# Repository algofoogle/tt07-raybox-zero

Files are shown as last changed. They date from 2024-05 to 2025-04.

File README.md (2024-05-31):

   

# raybox-zero for TT07 (Tiny Tapeout 07) - Resubmission updated from TT04

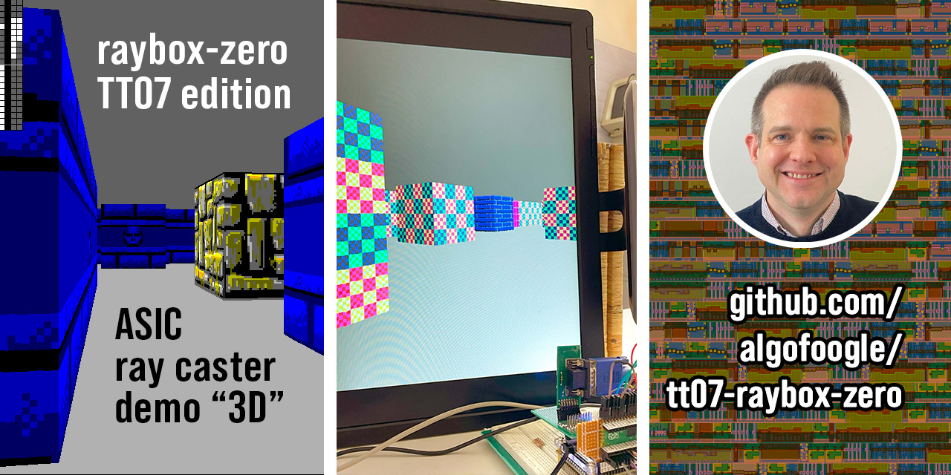
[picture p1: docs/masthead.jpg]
TT07 raybox-zero showing 3D views in simulation and on an FPGA


This is a resubmission of a very simple ray caster demo (sort of like Wolf3D rendering) driving a VGA display without a framebuffer (i.e. by 'racing the beam').

It was originally submitted to TT04, but due to a synthesis bug in the OpenLane flow, it produced severely glitchy output that I didn't discover until the chips came back from fabrication. Had I run a GL (gate-level) sim back in the day, I probably would've caught it, but maybe not had much I could do about it.

The version of OpenLane that TT07 uses doesn't seem to exhibit the same problem; I've since implemented GL sim, and both been able to prove the TT04 bug, and prove that it is gone in this TT07 version. NOTE: Extra special thanks goes to Uri Shaked and Matt Venn of [Tiny Tapeout](https://tinytapeout.com). The opportunity to do this was largely supported by the two of them, who graciously offered a resubmission after the TT04 synthesis bug (from OpenLane) had been observed to cause severe glitches in the rendering (due to an unintended alteration of the logic).

For more information:
- [Read the documentation for this project](docs/info.md) (WIP; [open an issue](https://github.com/algofoogle/tt07-raybox-zero/issues) to tell me what more you want to know)
- See the main source repo for this project: [algofoogle/raybox-zero]
- See [my journal](https://github.com/algofoogle/journal/blob/master/0204-2024-05-25.md) with some details about how I work on this locally.

[algofoogle/raybox-zero]: https://github.com/algofoogle/raybox-zero

## What is Tiny Tapeout?

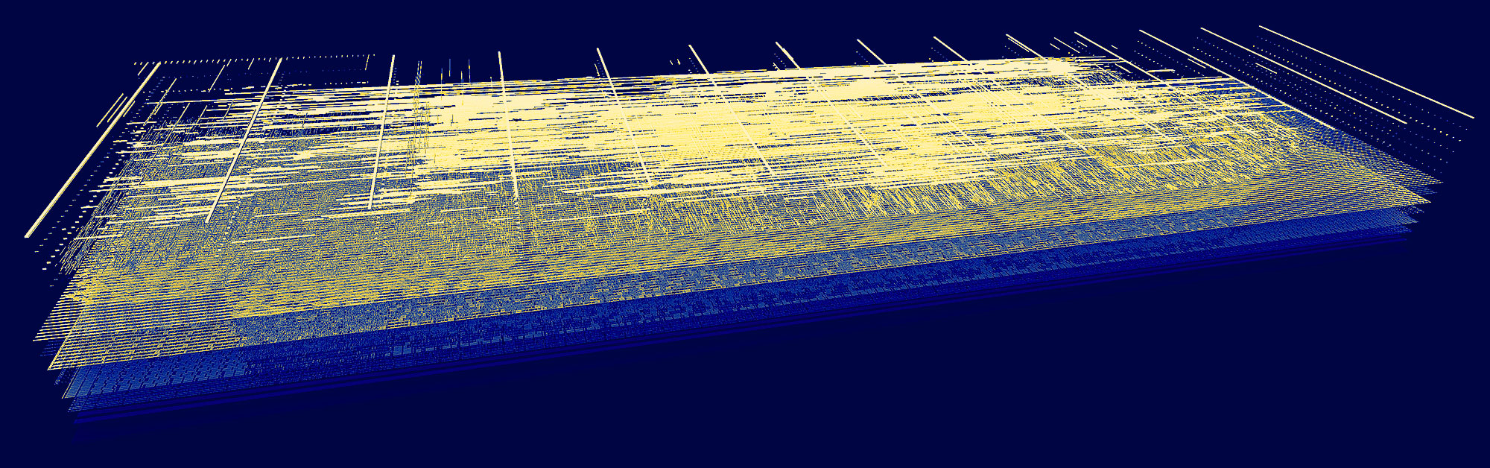
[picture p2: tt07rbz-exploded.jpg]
TT07 raybox-zero silicon layout (GDS) exploded view generated by Tiny Tapeout flow


Tiny Tapeout is an educational project that aims to make it easier and cheaper than ever to get your digital and analog designs manufactured on a real chip.

To learn more and get started, visit https://tinytapeout.com.

## Resources

- [FAQ](https://tinytapeout.com/faq/)
- [Digital design lessons](https://tinytapeout.com/digital_design/)
- [Learn how semiconductors work](https://tinytapeout.com/siliwiz/)
- [Join the community](https://tinytapeout.com/discord)
- [Build your design locally](https://docs.google.com/document/d/1aUUZ1jthRpg4QURIIyzlOaPWlmQzr-jBn3wZipVUPt4)

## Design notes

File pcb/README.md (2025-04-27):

# tt07-raybox-zero PCB(s)

This directory currently contains:

*   [`qspi-pmod-adapter/`](./qspi-pmod-adapter): Kicad PCB layout for a small adapter board that makes the [Tiny QSPI PMOD] work with tt07-raybox-zero. Can also just be used as a QSPI PMOD (if you solder U1 and C1).
*   [`Anton Kicad Footprints Lib.pretty/`](./Anton%20Kicad%20Footprints%20Lib.pretty/): Kicad footprints for PMOD connectors.

# Where to get the latest versions?

Each PCB and each revision I've had made has its own unique URL suffix silkscreened on the board.

For the latest version's files, see: https://github.com/algofoogle/tt07-raybox-zero/tree/main/pcb

Otherwise, see the [PCB revisions below](#pcb-revisions) to compare with the specific revision you have.

# PCB revisions

## `tt07a` QSPI adapter

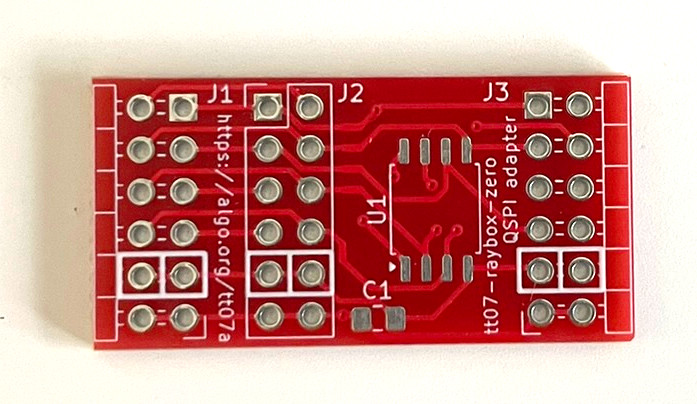
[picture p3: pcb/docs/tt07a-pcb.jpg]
tt07a QSPI adapter PCB photo


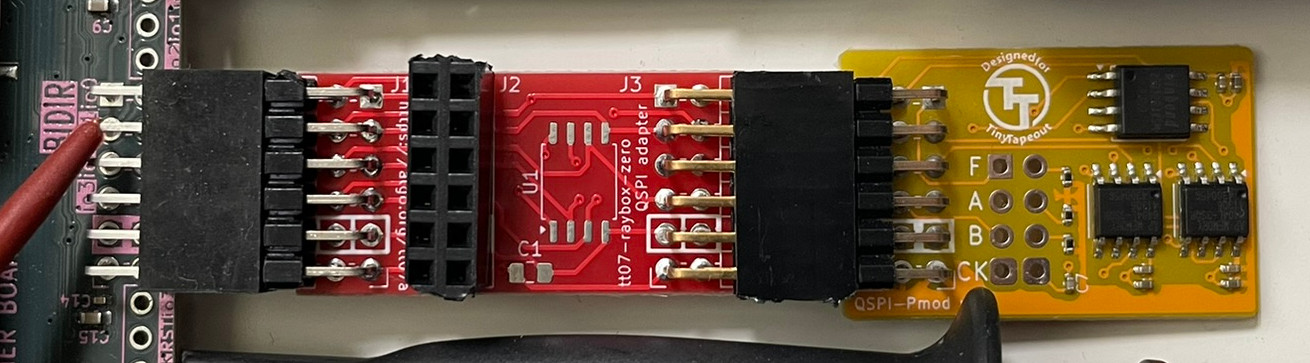
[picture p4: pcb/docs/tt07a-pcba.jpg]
tt07a QSPI adapter PCB assembled


This version of the board was my first prototype, intended to be demonstrated during the Tiny Tapeout 7 Bring-up Party live stream.

This board has a PMOD plug on only one end that is to remain plugged into the TT07 demo board's "Bidirectional" PMOD socket, and then the [Tiny QSPI PMOD] is meant to be alternated between the vertical slot (J2, for programming) and the edge slot (J3, for use with raybox-zero).

There is a footprint for an optional *on-board* QSPI chip, but it is not wired for being programmed by the [Tiny Tapeout Flasher](https://tinytapeout.github.io/tinytapeout-flasher/) utility, so would need to be wired up manually for programming.

[Commit `4ecdaab`](https://github.com/algofoogle/tt07-raybox-zero/tree/4ecdaabfdce3f8536820e55c5c4c37ef2575f69a/pcb/qspi-pmod-adapter) has the specific Gerber files that were fabricated.

[Tiny QSPI PMOD]: https://github.com/mole99/qspi-pmod

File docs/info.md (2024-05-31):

<!---

This file is used to generate your project datasheet. Please fill in the information below and delete any unused
sections.

You can also include images in this folder and reference them in the markdown. Each image must be less than
512 kb in size, and the combined size of all images must be less than 1 MB.
-->

TT07 raybox-zero showing 3D views in simulation and on an FPGA

## How it works

This is a framebuffer-less VGA display generator (i.e. it is 'racing the beam') that produces a simple
implementation of a "3D"-like ray casting game engine... just the graphics part of it.
It is inspired by Wolfenstein 3D, using a map that is a grid of wall blocks, with basic texture mapping.

There is nothing yet but textured walls, and flat-coloured floor and ceiling. No doors or sprites, sorry.
Maybe that will come in a future version (stay tuned for TT08 or some later release, maybe?)

The 'player' POV ("point of view") is controlled by SPI, which can be used to write the player position,
facing X/Y vector, and viewplane X/Y vector in one go.

NOTE: To optimise the design and make it work without a framebuffer, this renders what is effectively a
portrait view, rotated. A portrait monitor (i.e. one rotated 90 degrees anti-clockwise) will display this
like the conventional first-person shooter view, but it could still be used in a conventional landscape
orientation if you imagine it is for a game where you have a first-person perspective of a flat 2D
platformer, endless runner, "Descent-style" game, whatever.

NOTE: This is a resubmission of an updated version of what originally went to TT04. While the TT04 version used 4x2 tiles, this TT07 version adds some new features (namely the option for an external SPI texture ROM), and so uses 6x2 tiles (which is about 0.25mm<sup>2</sup>). The opportunity to do this was largely supported by Uri Shaked and Matt Venn of [Tiny Tapeout](https://tinytapeout.com), who graciously offered a resubmission after it was found that the TT04 version had suffered from a synthesis bug in an older version of OpenLane, which led to severe glitches in the rendering (due to an unintended alteration of the logic).

TBC. Please contact me if you want to know something in particular and I'll put it into the documentation!

## How to test

TBC. Please contact me if you want to know something in particular and I'll put it into the documentation!

Supply a clock in the range of 21-31.5MHz; 25.175MHz is ideal because this is meant to be "standard" VGA 640x480@59.94Hz.

Start with `gen_tex` set high, to use internally-generated textures. You can optionally attach an external QSPI memory (`tex_...`) for texture data instead, and then set `gen_tex` low to use it.

`debug` can be asserted to show current state of POV (point-of-view) registers, which might come in handy
when trying to debug SPI writes.

If `reg` input is high, VGA outputs are registered. Otherwise, they are just as they come out of internal combo logic.
I've done it this way so I can test the difference (if any).

`inc_px` and `inc_py` can be set high to continuously increment their respective player X/Y position register.
Normally the registers should be updated via SPI, but this allows someone to at least see a demo in action
without having to implement the SPI host controller. NOTE: Using either of these will suspend POV updates via SPI.

The "SPI2" ports (`reg_sclk`, etc.) are for access to all other registers that we can play with.
I decided to keep these separate because I implemented them very late, and didn't want to break the
existing SPI interface for POV register access.

## External hardware

Tiny VGA PMOD on dedicated outputs (`uo`).

Optional SPI controllers to drive `ui_in[2:0]` (point-of-view aka vectors) and `uio_in[4:2]` (other control/display registers).

Optional external SPI ROM for textures.

TBC. Please contact me if you want to know something in particular and I'll put it into the documentation!

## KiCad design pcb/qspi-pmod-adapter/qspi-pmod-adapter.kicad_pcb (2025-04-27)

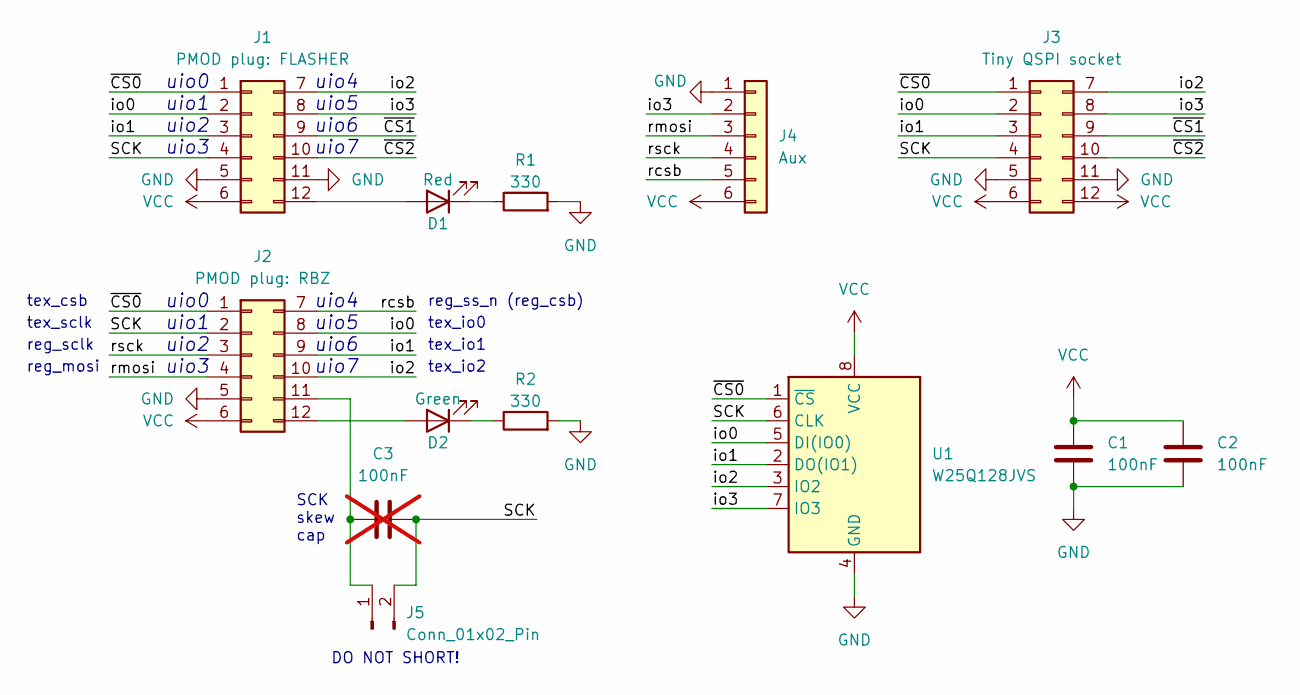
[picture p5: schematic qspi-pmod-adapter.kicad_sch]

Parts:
C1, C2: 100nF; C_0805_2012Metric_Pad1.18x1.45mm_HandSolder
C3: 100nF; C_0805_2012Metric_Pad1.18x1.45mm_HandSolder; not fitted
D1: Red; LED_0805_2012Metric_Pad1.15x1.40mm_HandSolder
D2: Green; LED_0805_2012Metric_Pad1.15x1.40mm_HandSolder
J1: PMOD plug: FLASHER; PinHeader_2x06_P2.54mm_PMODPeriph2B_Clip
J2: PMOD plug: RBZ; PinHeader_2x06_P2.54mm_PMODPeriph2B_Clip
J3: Tiny QSPI socket; PinSocket_2x06_P2.54mm_PMODPeriph2B_Vertical
J4: Aux; PinHeader_1x06_P2.54mm_Vertical
J5: Conn_01x02_Pin; PinHeader_1x02_P2.54mm_Vertical
R1, R2: 330; R_0805_2012Metric_Pad1.20x1.40mm_HandSolder
U1: W25Q128JVS; SOIC-8_5.23x5.23mm_P1.27mm

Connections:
/SCK: C3.2, J1.4, J2.2, J3.4, J5.2, U1.6 (CLK)
/io0: J1.2, J2.8, J3.2, U1.5 (DI(IO0))
/io1: J1.3, J2.9, J3.3, U1.2 (DO(IO1))
/io2: J1.7, J2.10, J3.7, U1.3 (IO2)
/io3: J1.8, J3.8, J4.2, U1.7 (IO3)
/rcsb: J2.7, J4.5
/rmosi: J2.4, J4.3
/rsck: J2.3, J4.4
/~CS0: J1.1, J2.1, J3.1, U1.1 (~CS)
/~CS1: J1.9, J3.9
/~CS2: J1.10, J3.10
GND: C1.2, C2.2, J1.5, J1.11, J2.5, J3.5, J3.11, J4.1, R1.2, R2.2, U1.4 (GND)
unnamed: D1.2 (A), J1.12
unnamed: D1.1 (K), R1.1
unnamed: D2.2 (A), J2.12
unnamed: D2.1 (K), R2.1
unnamed: C3.1, J2.11, J5.1
VCC: C1.1, C2.1, J1.6, J2.6, J3.6, J3.12, J4.6, U1.8 (VCC)

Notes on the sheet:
tex_sclk
tex_io1
uio4 uio5 uio6 uio7
DO NOT SHORT!
reg_ss_n (reg_csb)
uio0 uio1 uio2 uio3
tex_io0
reg_sclk
tex_io2
reg_mosi
SCK skew cap
tex_csb

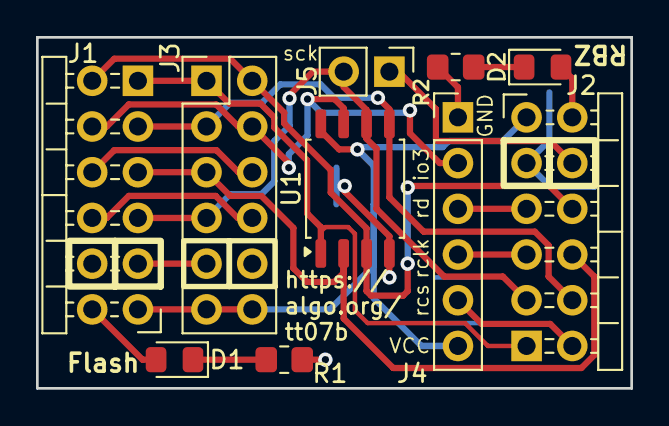
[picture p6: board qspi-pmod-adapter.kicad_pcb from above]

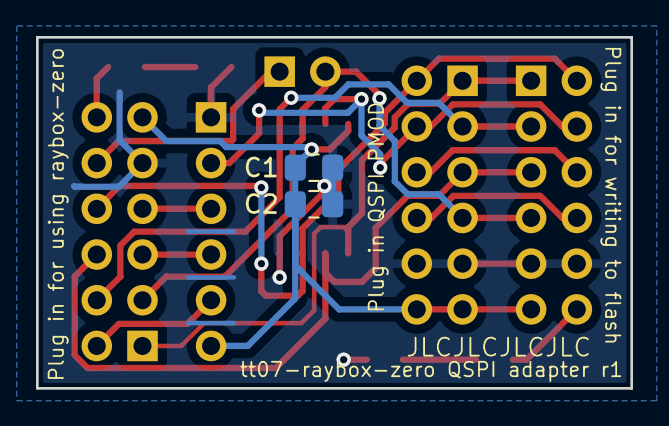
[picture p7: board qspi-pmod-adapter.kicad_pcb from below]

Board: 2 copper layers, 33.0 x 19.5 mm, 12 parts (2 on the bottom side), 18 nets.

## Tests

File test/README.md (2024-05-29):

# `test/`: Files supporting basic cocotb automated tests

This builds on:
* https://github.com/algofoogle/tt05-vga-spi-rom/tree/main/src/test
* https://github.com/algofoogle/tt04-raybox-zero/tree/1.0-test/src/test
* https://github.com/TinyTapeout/tt07-verilog-template/tree/main/test

For other background on this, see [0197], [0198], and [0204].

**To actually run the tests,** go into this `test/` directory (i.e. where the `Makefile` is) and run `make -B`.

## More information

[0204] now probably has my most comprehensive notes on how to set up your environment for local hardening and testing. Note that it includes lots of stuff from my original TT04 re-testing, but further down on the page are the additional details that work for this repo and TT07.

If you run `make clean && make -B` it will run the RTL test. These render frames on my machine at about 26 seconds each.

If you run `make clean && make -B GATES=yes` it will run the GL (gate-level) test. These take about 70 seconds per frame.

Frame output files are `test/rbz_basic_frame-???.ppm`.

NOTE: If you change the RTL and want to do GL, remember that you'll need to reharden and then copy `../runs/wokwi/results/final/verilog/gl/tt_um_algofoogle_raybox_zero.v` to `./gate_level_netlist.v`.

[0197]: https://github.com/algofoogle/journal/blob/master/0197-2024-04-02.md
[0198]: https://github.com/algofoogle/journal/blob/master/0198-2024-04-03.md
[0204]: https://github.com/algofoogle/journal/blob/master/0204-2024-05-25.md

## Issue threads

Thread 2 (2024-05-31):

How to run Gate level test and output rendering frames?

pongsagon, 2024-05-31:
Hi,
I have read your recent journal but cannot really understand the step to do the GL test and get the output render frames.  I am quite novice in the ASIC workflow.
To be able to do this test would be super helpful.  The tutorial should be added on the TinyTapeout official website!
The best thing I can do is only to test my design on the FPGA and hope that it would work on the ASIC.

Thanks a lot for your write up.

algofoogle, 2024-06-12:
Sorry, I overlooked this earlier. I'll try to do a better write-up soon (and I'm planning on creating a bit of a proposal for how to formalise this for Tiny Tapeout). For now though I can give you these pointers:
1. My frame-rendering test code works for both RTL (behavioural Verilog code) and GL (sky130 gate-level code) simulation. RTL is fast, GL is slow (but fairly accurate for actual expected silicon results, but not for timing for things like setup/hold violations).
2. Running this locally (which is a great idea) depends on you being able to harden your TT design locally, and [there's a new TT08 guide for that](https://www.tinytapeout.com/guides/local-hardening/) -- TT07 and below had slightly different instructions, which I cover in my various recent journal entries. I can share that too, if you want to prove something prior to TT08. NOTE: For GL simulation, after you harden, you need to copy the gate-level netlist (Verilog) file into the `test` directory, if using my test. This is referenced [here](https://github.com/algofoogle/tt07-raybox-zero/blob/52f0c950ce848645954d855fd43489ddb16e0dc4/test/Makefile#L48). The GitHub Action (described below) does this copying automatically.
3. There is an existing [gate-level GitHub Action](https://github.com/algofoogle/tt07-raybox-zero/blob/52f0c950ce848645954d855fd43489ddb16e0dc4/.github/workflows/gds.yaml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) as part of TT projects (I haven't checked whether this has changed for TT08+) and this just runs whatever configured cocotb test(s) you already have. In my case the action includes the extra `FRAMES: 5` environment variable that my cocotb test is able to use (and there are others available in my test).
4. My actual test that renders frames is found in [test/test.py](https://github.com/algofoogle/tt07-raybox-zero/blob/52f0c950ce848645954d855fd43489ddb16e0dc4/test/test.py#L130) -- it just runs a 25MHz clock, resets the design, samples video signal outputs on each clock cycle (i.e. each pixel), and then writes out an old-fashioned uncompressed [PPM file](https://en.wikipedia.org/wiki/Netpbm#PPM_example) for each frame. It keeps track of the current pixel (clock) count, to know that when 800 cycles have elapsed, that's the equivalent of one full VGA line (at 640x480 resolution), and 525 lines equal 1 frame. There is also code that runs in parallel (coroutine) to twiddle inputs to my SPI interfaces, which my design uses for controlling the state/view of what I want it to render, and I've got an if/else chain that decides which feature I want to exercise for each frame. Note that there is also code to sense when an output is in a **simulation-unknown** state or Hi-Z, and in my case I've decided to count those as "bad" pixels, and render them as bright green or magenta (respectively) to make them stand out. I ended up having to add a lot of extra reset logic that I didn't expect I'd need, in order to weed out these unknown states, and that was where GL simulation was vital.
5. Finally, having a [test/tb.v](https://github.com/algofoogle/tt07-raybox-zero/blob/main/test/tb.v) that assigns meaningful variable/signal names to your TT ports is important both to ensure they're available to cocotb, and that their names make sense to you when writing the tests. Note two more things in my case: (1) I've also got an SPI ROM simulator hooked up to my design in this file; and (2) I disable VCD dumps because these end up being MASSIVE (gigabytes) when simulating entire VGA frames at gate-level.

algofoogle, 2024-06-12:
See also: https://github.com/algofoogle/tt07-raybox-zero/blob/main/test/README.md

pongsagon, 2024-06-15:
Thank you for your detail explanation.
It would be a valuable resource for the TT community.

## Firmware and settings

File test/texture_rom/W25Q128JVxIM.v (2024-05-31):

/******************************************************************************
 Winbond Electronics Corporation
 Verilog Model for W25Q128JVxIM Serial Flash Memory

 V1.0-beta

 Copyright (c) 2001-2016 Winbond Electronics Corporation
 All Rights Reserved.

                         Author/Support: Mike Chen                         
                         Email: mchen4@winbond.com                          

 Versions:
	01/30/2016	V1.0-beta	Initial Version

******************************************************************************/

`timescale 1ns / 1ns

module W25Q128JVxIM (CSn, CLK, DIO, DO, WPn, HOLDn);
input CSn, CLK;
inout DIO;
inout WPn;
inout HOLDn;
inout DO;

parameter NUM_PAGES = 65536;
parameter NUM_SEC_PAGES = 3;
parameter PAGESIZE  = 256;
parameter SECTORSIZE = 4096;
parameter HALFBLOCKSIZE = 32768;
parameter BLOCKSIZE = 65536;
parameter NUM_BLOCKS = NUM_PAGES * PAGESIZE / BLOCKSIZE;
parameter NUM_LOCKBITS = NUM_BLOCKS - 2 + 32;
parameter MANUFACTURER = 8'hEF;
parameter DEVICE_ID	= 8'h17;
parameter JEDEC_ID_HI = 8'h70;
parameter JEDEC_ID_LO = 8'h18;
parameter UNIQUE_ID = 64'h0102030405060708;
parameter ADDRESS_MASK = (NUM_PAGES * PAGESIZE) - 1;		// Note that NUM_PAGES must be a power of 2 for this simulation to work properly.

`define MEM_FILENAME    "texture_rom/texture_memory.hex"   // Memory contents file(s)
`define SECSI_FILENAME  "texture_rom/secsi.hex"
`define SFDP_FILENAME   "texture_rom/sfdp.hex"
`define SREG_FILENAME   "texture_rom/sreg.hex"


// The following registers define the main memory spaces of the device.
//
//

reg [7:0] memory [0:(NUM_PAGES * PAGESIZE) - 1];	                        // Main Memory Array
reg [7:0] page_latch [0:PAGESIZE-1];                                       	// Page Latch for Program Sector commands.
reg [7:0] secsi[0:(NUM_SEC_PAGES * (SECTORSIZE/PAGESIZE) * PAGESIZE) - 1]; 	// Security Sector Array
reg [7:0] sfdp[0:PAGESIZE];                                                	// Serial Flash Discoverable Parameter
reg lock_array[0:NUM_LOCKBITS-1];                                            	// 510 blocks + 32 sectors

reg [23:0] status_reg;				      				// Status Register
reg [23:0] status_reg_shadow;							// Status Register Shadow Register
reg status_reg_otp [23:0];      						// Status Register OTP Bits 
reg [23:0] byte_address;				    			// Page address used for reading pages. 
reg [23:0] prog_byte_address;   						// Page address used for writing pages.
reg [7:0] mode_reg;					        		// Mode Register
reg [7:0] wrap_reg;             						// burst-wrap register
reg [7:0] read_param_reg;        						// Read parameters register
reg [7:0] read_param_reg_shadow; 						// Shadow register

reg flag_prog_page;         			// Flag used to start the program process for sram 0
reg flag_prog_secsi_page;        		// Flag used to program a SECSI page
reg flag_erase_sector;				// Flag used to erase a sector (4KB)
reg flag_erase_secsi_sector;
reg flag_erase_half_block;			// Flag to erase half a block (32KB)
reg flag_erase_block;				// Flag used to erase a block (64KB)
reg flag_erase_bulk;				// Flag used to erase the chip
reg flag_power_up_exec;
reg flag_power_down;
reg flag_power_up_sig_read;
reg flag_write_status_reg;
reg flag_suspend;               		// Flag used to start an erase suspend process.
reg flag_resume;                		// Flag used to resume from and erase suspend
reg flag_suspend_enabled;       		// Flag used to stop the erase process.
reg flag_slow_read_reg;
wire flag_slow_read = flag_slow_read_reg;
reg flag_volatile_sr_write;     		// flag for volatile status register write.
reg flag_read_op_reg;
wire #1 flag_read_op = flag_read_op_reg;   	// Delay avoids race condition
reg flag_qpi_mode;             			// flag used for QPI Mode.
reg flag_enable_reset;         			// flag used to enable the software reset command.
reg flag_reset;                			// flag to execute the chip reset routine
reg flag_reset_condition;      			// Flag to stop delay loops
reg flag_set_read_param;       			// Flag to set read parameters

reg timing_error;				// Register for identifying timing errors when they occur

reg [7:0] in_byte;				// These two variables are used for debug purposes.
reg [7:0] out_byte;

// Logic output for WPn pin.
//
reg WPn_Reg, WPn_Output_Enable_reg; 
wire WPn_Output_Enable = WPn_Output_Enable_reg;

// Logic output for HOLDn pin.
//
reg HOLDn_Reg, HOLDn_Output_Enable; 

// Logic output for DO pin.
//
reg DO_Reg, DO_Output_Enable, temp_DO_Output_Enable;

// Logic output for DIO pin.
// 
reg DIO_Reg, DIO_Output_Enable_reg, temp_DIO_Output_Enable_reg;
wire DIO_Output_Enable = DIO_Output_Enable_reg;

// Flag to signal that HOLDn goes active while CSn is low
reg HOLDn_Active;

// The following are working variables for the simulation program
//

reg [7:0]  cmd_byte;
reg [7:0]  null_reg;
reg [7:0]  temp;

integer  x;
integer	 fileno;
reg [15:0] file_sector;
reg [15:0] file_length;


// The following macro's define the supported commands in this
// Simulation
//
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

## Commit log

2024-05-30 Add test/frames_out, hopefully fix GHA CI
2024-05-30 Trying to fix GHAs for storing frames
2024-05-30 Wire up raybox-zero '1.5'; RTL sim works. No harden yet
2024-05-31 1.5-dev: Better tests inc. SPI coroutines; doco updates [no ci]
2025-04-07 Tiny QSPI PMOD adapter PCB [no ci]
    [qspi-pmod-adapter-B_Cu.gbl, qspi-pmod-adapter-B_Mask.gbs, qspi-pmod-adapter-B_Paste.gbp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]
2025-04-27 README for tt07a PCB revision [no-ci]
2025-04-27 Pin ubuntu-22.04 for GitHub Actions
2025-04-27 tt07b (r1) PCB revision: QSPI adapter dual-plug [no ci]
    [qspi-pmod-adapter-B_Cu.gbl, qspi-pmod-adapter-B_Mask.gbs, qspi-pmod-adapter-B_Paste.gbp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]
